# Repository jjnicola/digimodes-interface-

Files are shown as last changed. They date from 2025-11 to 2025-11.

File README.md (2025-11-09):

# digimodes-interface

Digimodes interfaces for old analog transcievers without VOX functionality. It requires to be powered to activate the PTT while sending audio from computer.
The first transistor in the schematic amplifies the audio signal. The following is the rectifier diode on filters. This diode must be a germanium diode because its 0.3volts threshold voltage.

This was design specially for an Icom IC-725 to be connected in the mic connector, which provides an 8 volts low current (max 10mA) outout in one of the pins. It can be also used in the ACC1 connector, which provides also a 13.8v output. I checked the Yaesu FT-80c and it should work as well since it provides all input/outputs for this 
If your transciever doesn't have a Vcc output, you can use a 9v battery.

Special thanks to LU5VV for all the support and the initial desing.

LU6VJN

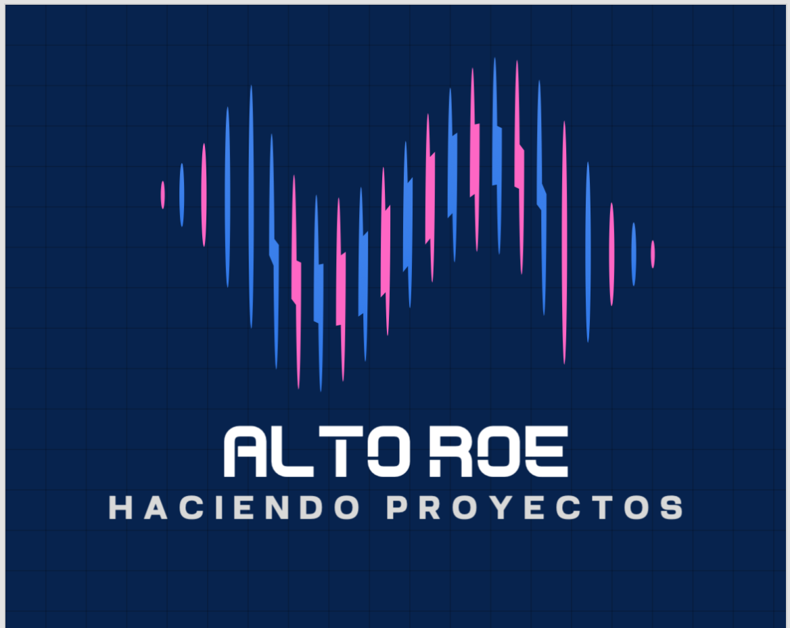
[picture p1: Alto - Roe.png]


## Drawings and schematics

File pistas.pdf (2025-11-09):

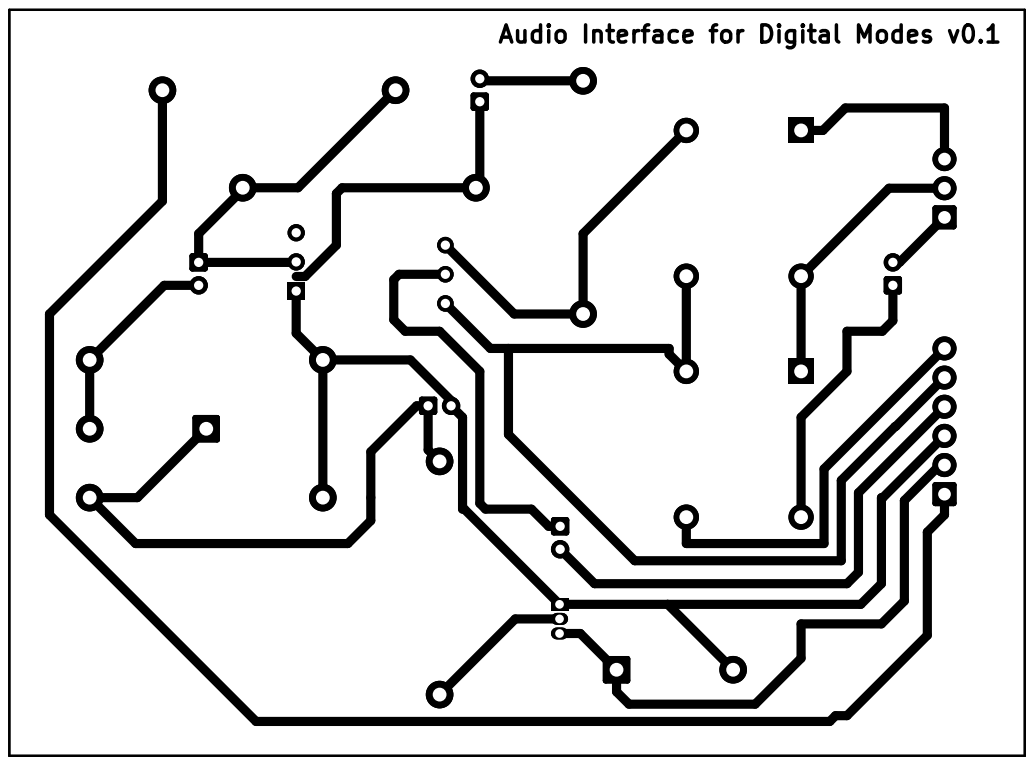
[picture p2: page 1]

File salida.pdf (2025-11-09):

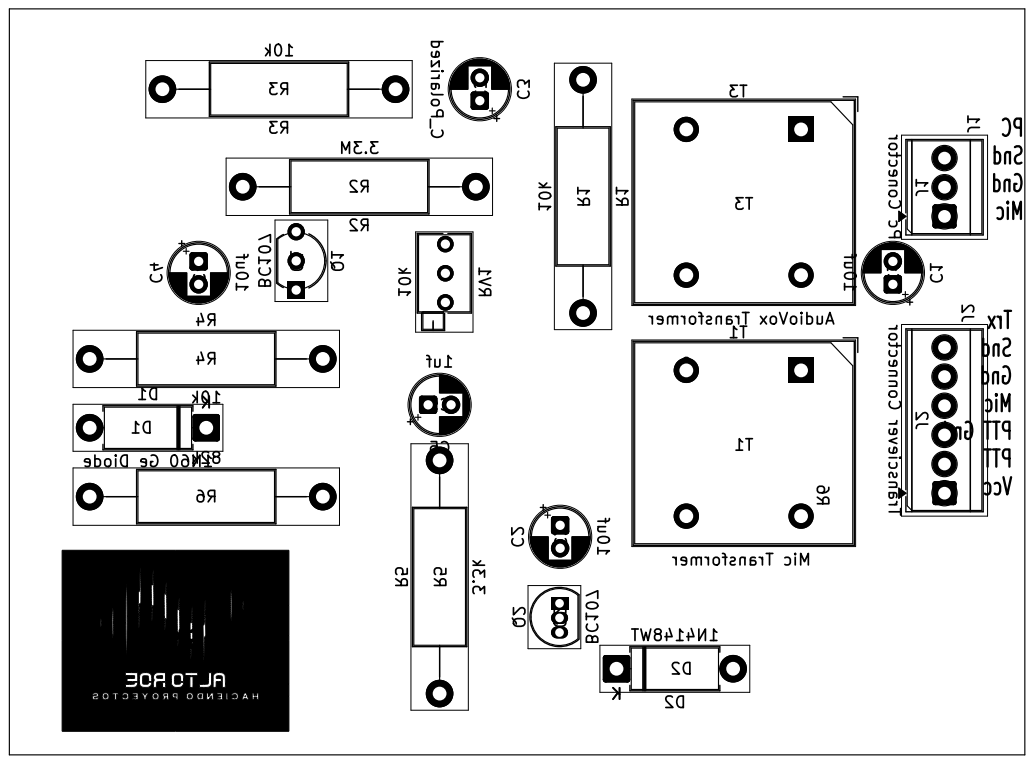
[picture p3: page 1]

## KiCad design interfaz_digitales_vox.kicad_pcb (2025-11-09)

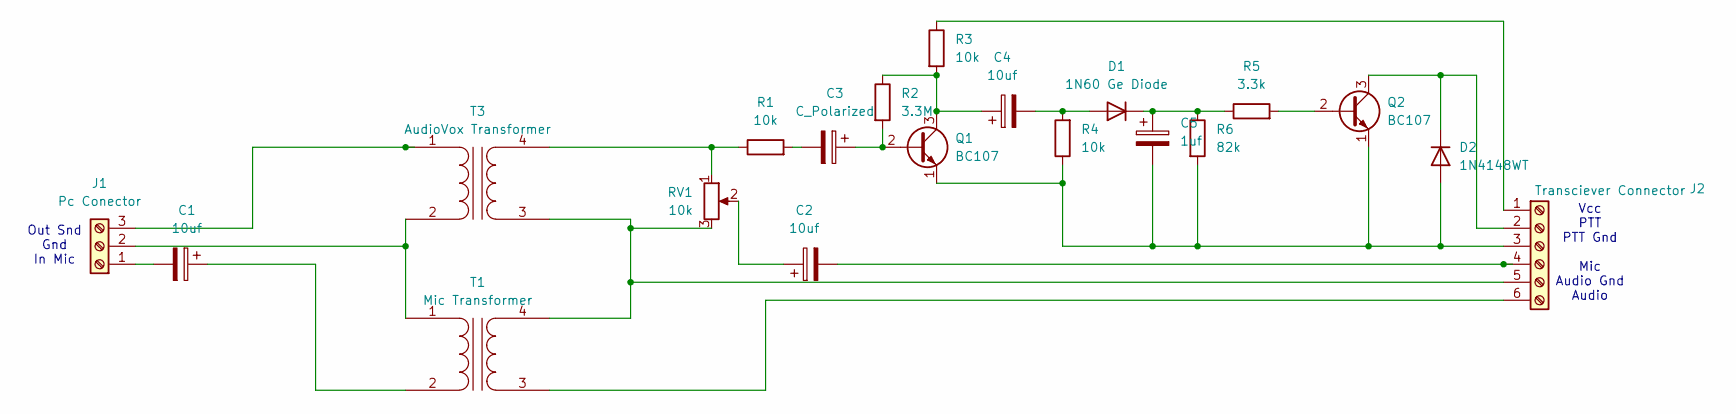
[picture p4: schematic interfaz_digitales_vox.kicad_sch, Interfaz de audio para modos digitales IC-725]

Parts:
C1, C2, C4: 10uf; CP_Radial_D5.0mm_P2.00mm
C3: C_Polarized; CP_Radial_D5.0mm_P2.00mm
C5: 1uf; CP_Radial_D5.0mm_P2.00mm
D1: 1N60 Ge Diode; D_DO-15_P10.16mm_Horizontal
D2: 1N4148WT; D_DO-15_P10.16mm_Horizontal
J1: Pc Conector; TerminalBlock_TE_282834-3_1x03_P2.54mm_Horizontal
J2: Transciever Connector; TerminalBlock_TE_282834-6_1x06_P2.54mm_Horizontal
Q1: BC107; TO-92L_Inline_Wide
Q2: BC107; TO-92L_Inline
R1, R3, R4: 10k; R_Axial_DIN0414_L11.9mm_D4.5mm_P20.32mm_Horizontal
R2: 3.3M; R_Axial_DIN0414_L11.9mm_D4.5mm_P20.32mm_Horizontal
R5: 3.3k; R_Axial_DIN0414_L11.9mm_D4.5mm_P20.32mm_Horizontal
R6: 82k; R_Axial_DIN0414_L11.9mm_D4.5mm_P20.32mm_Horizontal
RV1: 10k; Potentiometer_Bourns_3266Z_Horizontal
T1: Mic Transformer; Transformer_Zeming_ZMPT101K
T3: AudioVox Transformer; Transformer_Zeming_ZMPT101K

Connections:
unnamed: C2.1, RV1.2
unnamed: C3.2, R1.2
unnamed: C4.2, D1.2 (A), R4.2
unnamed: C5.1, D1.1 (K), R5.1, R6.1
unnamed: C5.2, D2.2 (A), J2.3, Q1.1 (E), Q2.1 (E), R4.1, R6.2
unnamed: D2.1 (K), J2.2, Q2.3 (C)
unnamed: C1.2, J1.1
unnamed: J1.2, T1.1 (AA), T3.2 (AB)
unnamed: J1.3, T3.1 (AA)
unnamed: J2.1, R3.1
unnamed: C2.2, J2.4
unnamed: J2.5, RV1.3, T1.4 (SB), T3.3 (SA)
unnamed: J2.6, T1.3 (SA)
unnamed: C3.1, Q1.2 (B), R2.2
unnamed: C4.1, Q1.3 (C), R2.1, R3.2
unnamed: Q2.2 (B), R5.2
unnamed: C1.1, T1.2 (AB)
unnamed: R1.1, RV1.1, T3.4 (SB)

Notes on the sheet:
Out Snd Gnd In Mic
Vcc PTT PTT Gnd Mic Audio Gnd Audio

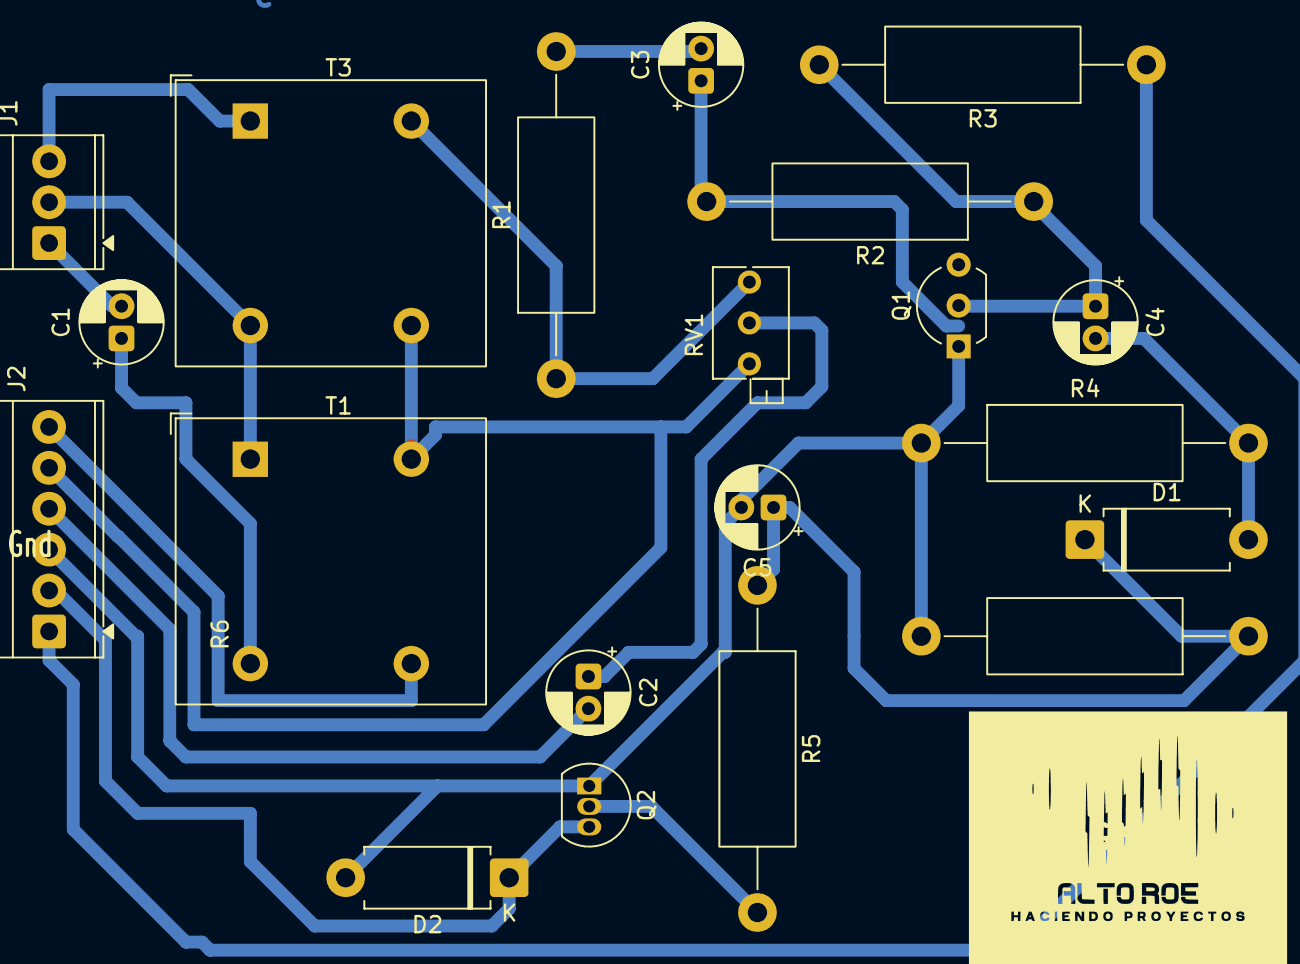
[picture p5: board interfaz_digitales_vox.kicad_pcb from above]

Board: 2 copper layers, 20 parts (0 on the bottom side), 18 nets.
